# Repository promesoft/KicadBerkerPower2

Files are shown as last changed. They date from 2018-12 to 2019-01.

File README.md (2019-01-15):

# KicadBerkerPower2
Black board

# Mix project
The board consists of 5 separate sections that can be separated. On the backside its easy to see the different ground planes and where to cut the board if needed.

## Status - Rev A Produced 3 of 5 sections working
### Errata
 * Copper goes under ESP12E modules - thereby eliminating the Wifi antenna...
 
### Issues and Notes
 - The two ESP12 modules are difficult to program

 - The Wemos D1 mini section should not be used for 230V but works nevertheless.

 - The rest is fine.

## Physical Construction

## Features

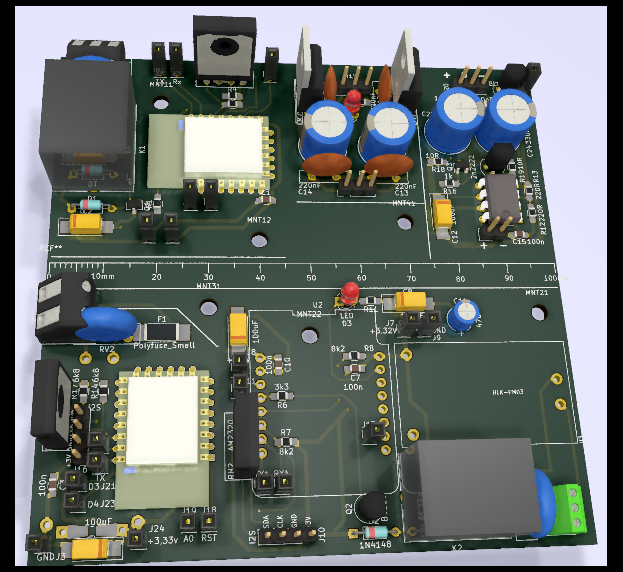
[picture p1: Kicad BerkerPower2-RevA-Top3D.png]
Power

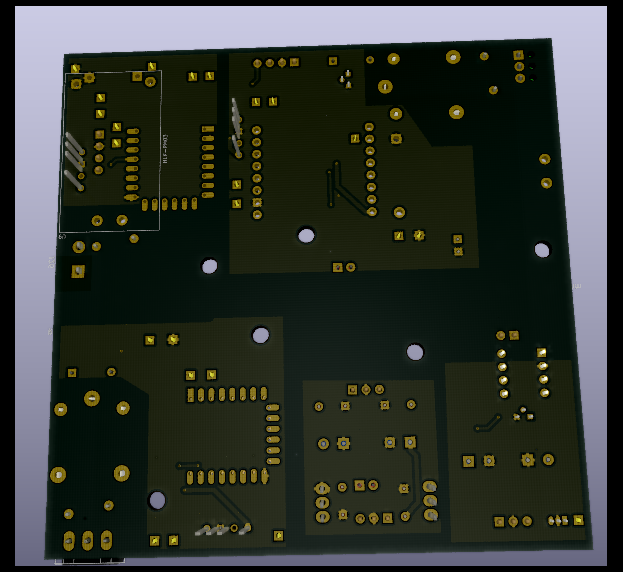
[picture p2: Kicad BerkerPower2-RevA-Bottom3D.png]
Power


# Details
## Wemos D1 mini - section 1
Section 1 is the largest section on the board. It is intended as a development board for section 2 and 3.
Section 1 has an AM2320, a relay and a power supply. Besides this it has breakout of several pins and an LED for debug/information.
### Issues
There is one flaw with section 1 that should be addressed: The pins on the power connector are too close for 230V operation as the centerpin of the relay bridges the live and neutral (calculated to be min 2,3mm between open terminals - 3,2mm for certification) 

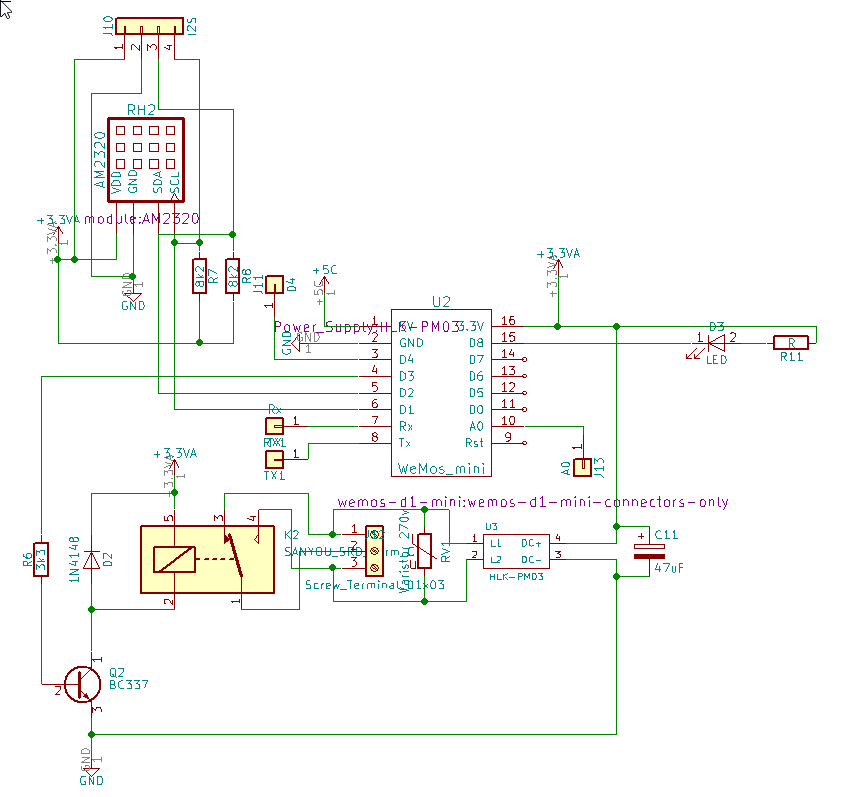
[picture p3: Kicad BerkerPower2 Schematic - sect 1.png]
Section1

### I2S connector 
D1 - SCL

D2 - SDA
### AM2320 
D1 - SCL

D2 - SDA
### Relay
D3 - Active high
### HLK-PM03 PSU
+3v PSU supply if mounted 
Connector not suitable for 230V
Protection: Varistor
External Fuse needed
### Pull down LED
D8 - active low
## ESP12S - Section 2
Section 2 is the smaller than section 1 but with most features of it.
### AM2320 
### Relay
### HLK-PM03 PSU
## ESP12S - Section 3
No reset or programming assistance (pulldn/up etc)
Programming via Rx/Tx (or preprogrammed)
### AM2320 
### Relay
### HLK-PM03 PSU
## PSU - Virtual GDN - "Floating ground section"
Sometimes you only have a single ended supply but need a positive and negative supply.
This little board provides a low power balanced center that can be used as GND. So a +24 V single ended supply becomes a +/-12V supply.

### Input +/- supply
eg +24Vin and a "GNDin"
### Output + 0 - supply
becomes a +12V (same as +24in) GND and -12V (same as GNDin)
### Output regulated +5v GND (78L05)
The +12Vout is fed to a low power regulator for 5V output
## PSU
### Input + 0 - supply
### Output + 0 - regulated supply (78xx and 79xx)

#Cutout

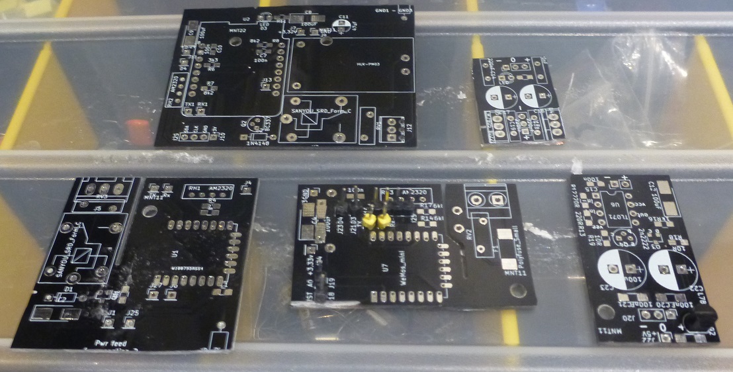
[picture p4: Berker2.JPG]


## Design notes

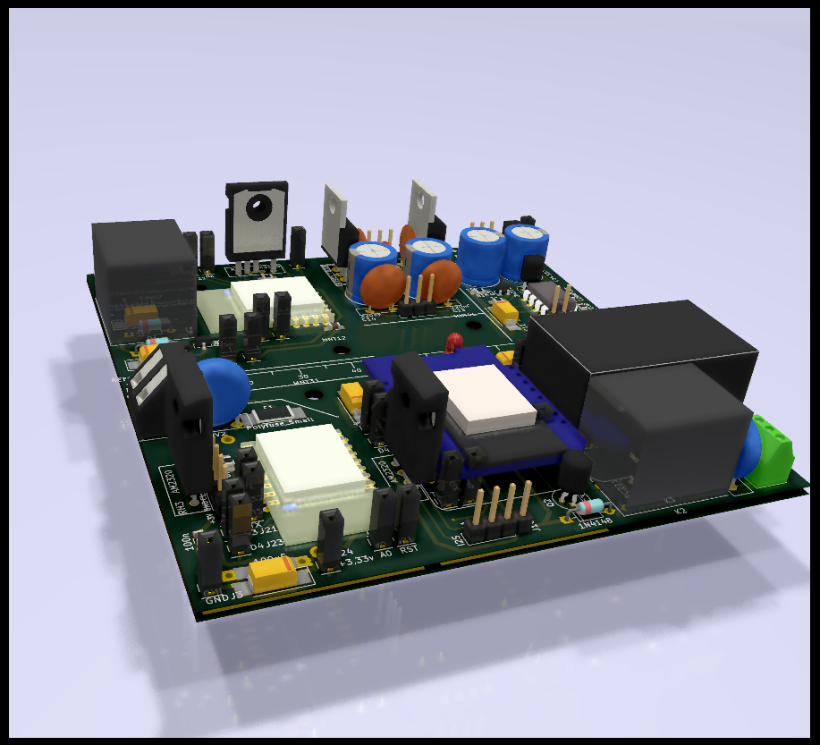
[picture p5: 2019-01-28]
Kicad BerkerPower2-RevA-Top3D2.png

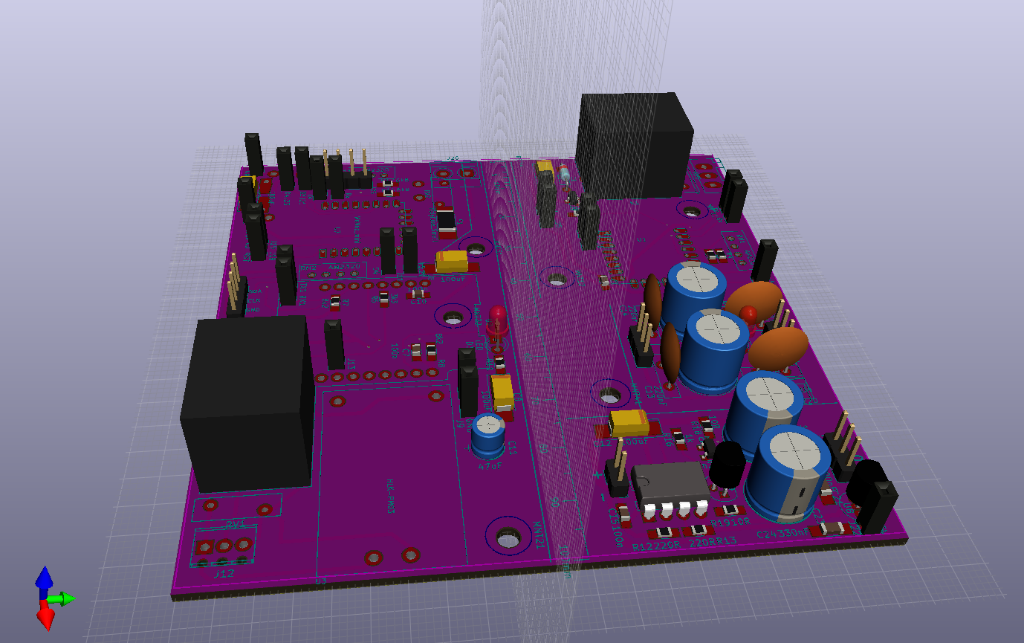
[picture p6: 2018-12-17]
Kicad BerkerPower2 3D.png

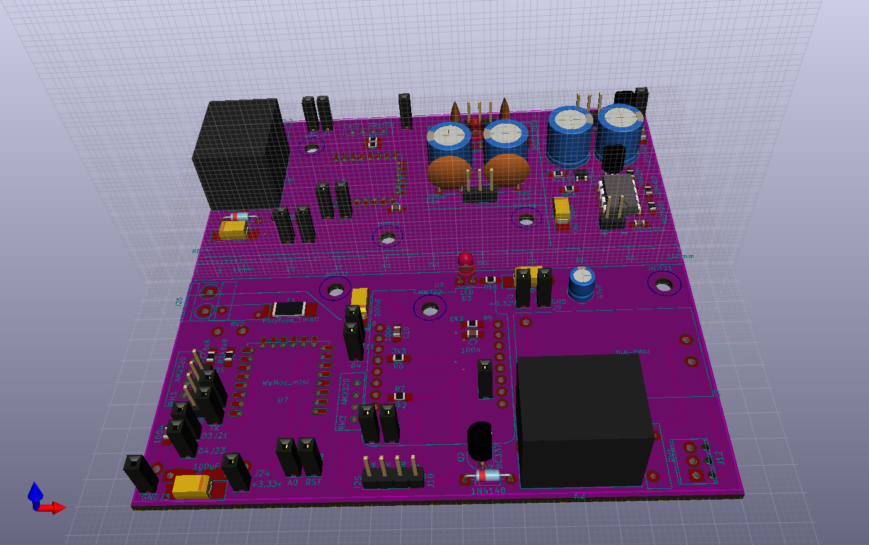
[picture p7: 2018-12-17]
Kicad BerkerPower2a 3D.png

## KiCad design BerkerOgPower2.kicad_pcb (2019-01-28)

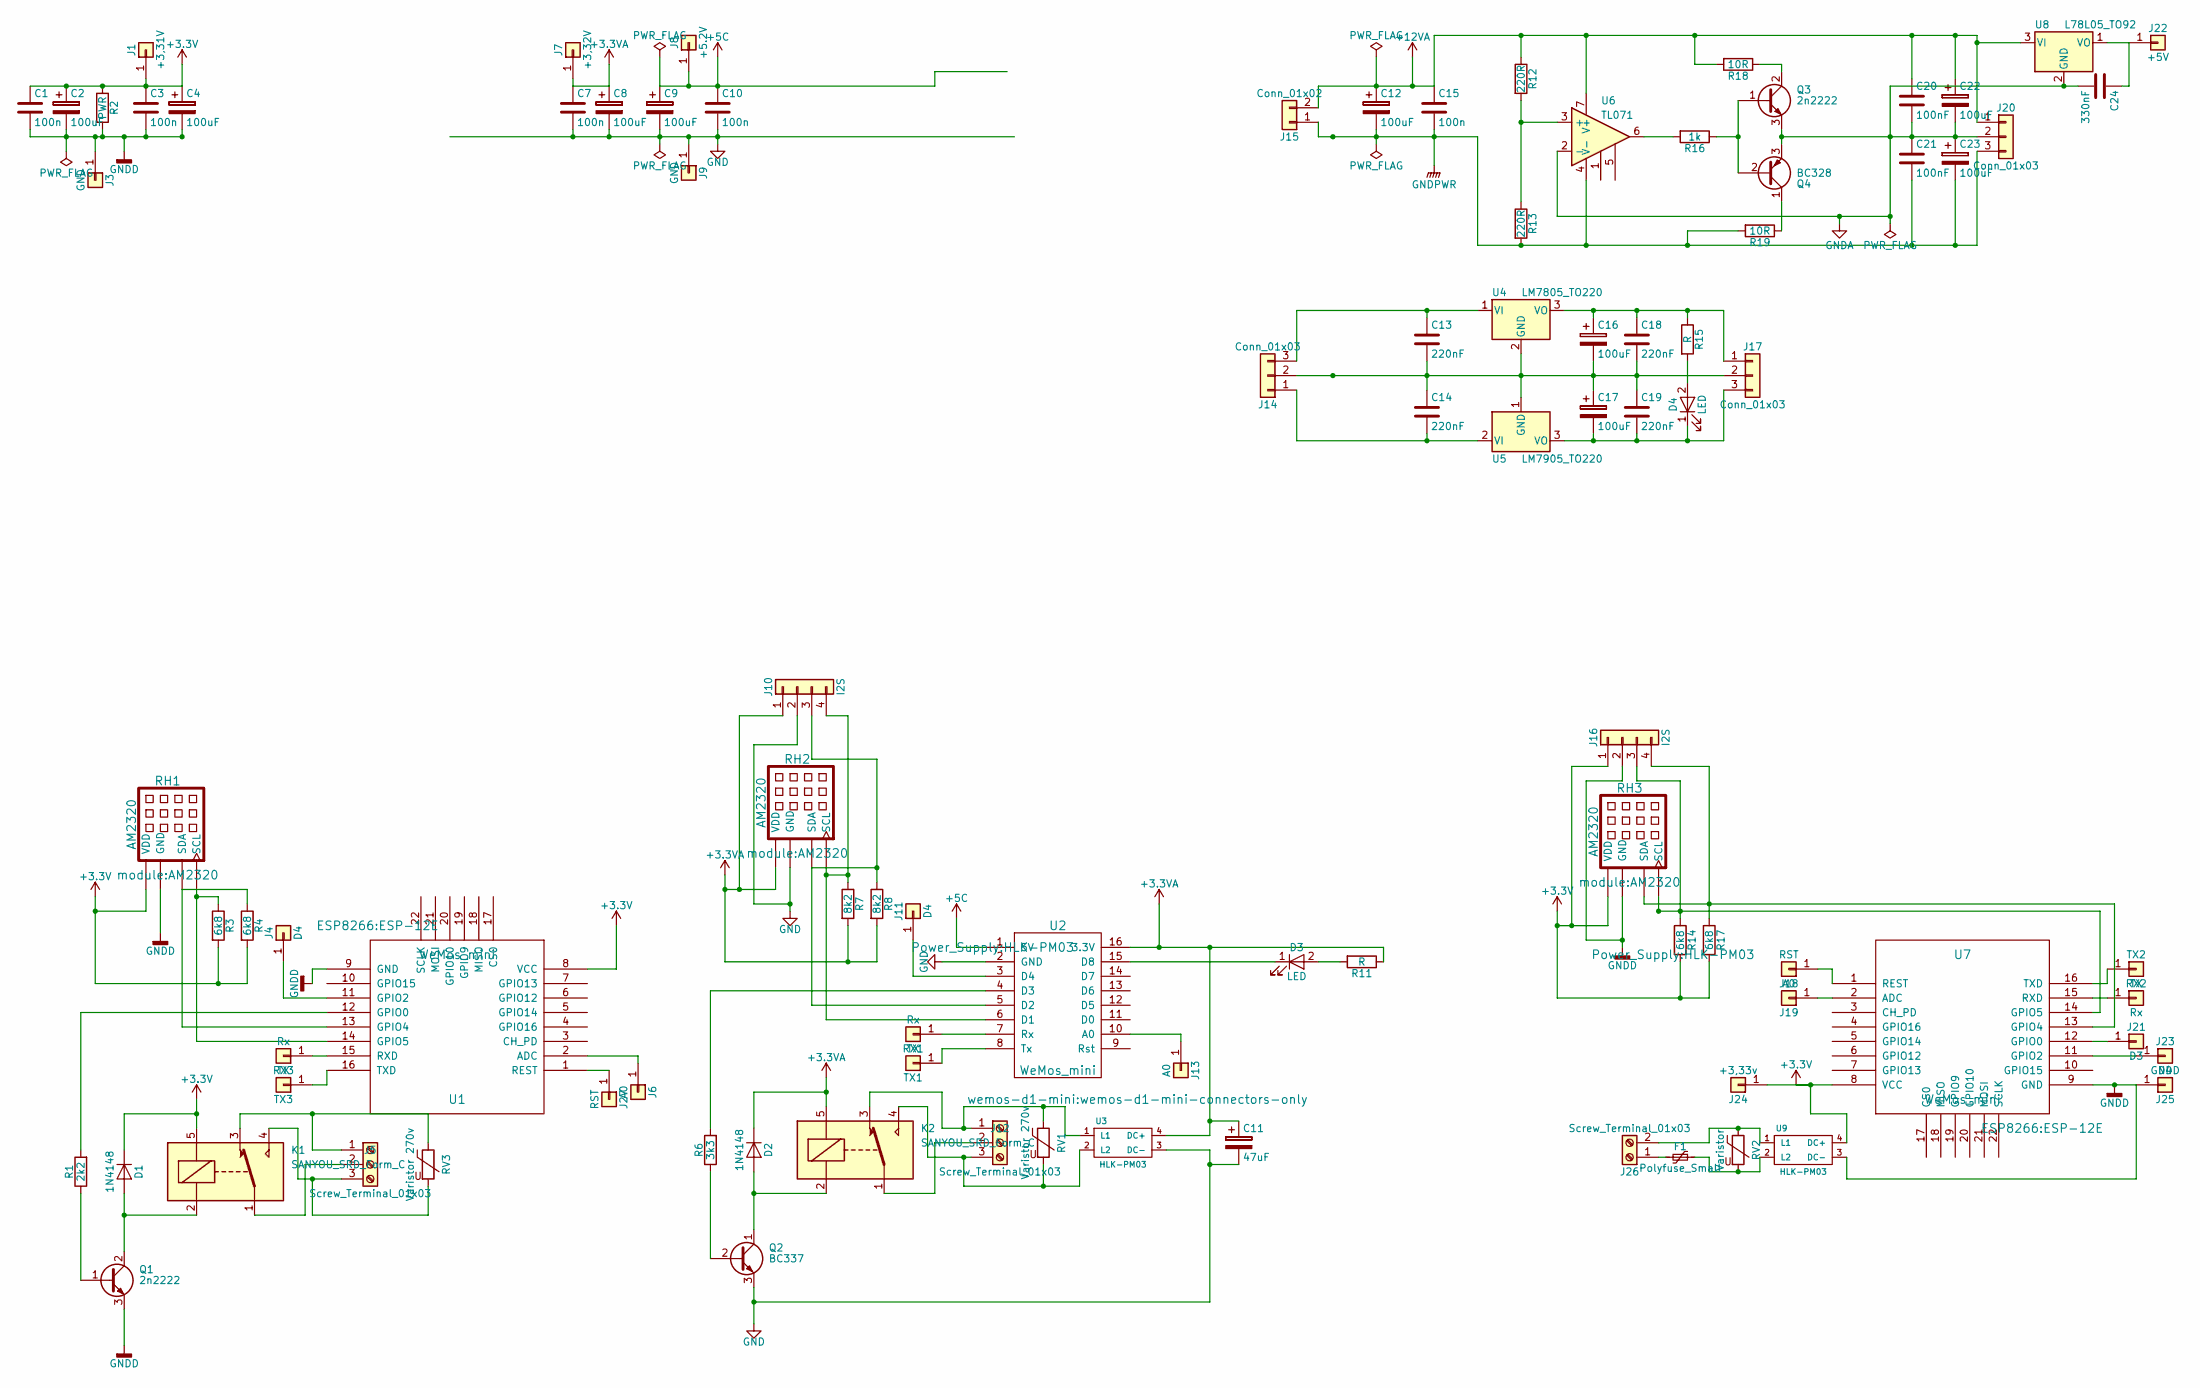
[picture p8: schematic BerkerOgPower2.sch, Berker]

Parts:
C1, C3, C7, C10, C15: 100n; C_0805_HandSoldering
C2, C4, C8, C9, C12: 100uF; CP_Tantalum_Case-C_EIA-6032-28_Hand
C11: 47uF; CP_Radial_D5.0mm_P2.50mm
C13, C14, C18, C19: 220nF; C_Disc_D10.0mm_W2.5mm_P5.00mm
C16, C17, C22, C23: 100uF; CP_Radial_D10.0mm_P3.80mm
C20, C21: 100nF; C_1206_HandSoldering
C24: 330nF; C_1206_HandSoldering
D1, D2: 1N4148; D_DO-35_SOD27_P7.62mm_Horizontal
D3, D4: LED; LED_D3.0mm
F1: Polyfuse_Small; R_2512_HandSoldering
J1: +3,31V; Socket_Strip_Straight_1x01_Pitch2.54mm
J3, J9: GND; Socket_Strip_Straight_1x01_Pitch2.54mm
J4, J11, J23: D4; Socket_Strip_Straight_1x01_Pitch2.54mm
J5: Screw_Terminal_01x03; WAGO_734_3pin_Straight_RuggedPads
J6, J13, J19: A0; Socket_Strip_Straight_1x01_Pitch2.54mm
J7: +3,32V; Socket_Strip_Straight_1x01_Pitch2.54mm
J8: +5.2V; Socket_Strip_Straight_1x01_Pitch2.54mm
J10, J16: I2S; Pin_Header_Straight_1x04_Pitch2.54mm
J12: Screw_Terminal_01x03; TerminalBlock_Phoenix_MPT-2.54mm_3pol
J14, J17, J20: Conn_01x03; Pin_Header_Straight_1x03_Pitch2.54mm
J15: Conn_01x02; Pin_Header_Straight_1x02_Pitch2.54mm
J18, J27: RST; Socket_Strip_Straight_1x01_Pitch2.54mm
J21: D3; Socket_Strip_Straight_1x01_Pitch2.54mm
J22: +5V; Socket_Strip_Straight_1x01_Pitch2.54mm
J24: +3,33v; Socket_Strip_Straight_1x01_Pitch2.54mm
J25: GNDD; Socket_Strip_Straight_1x01_Pitch2.54mm
J26: Screw_Terminal_01x03; TerminalBlock_Phoenix_MKDS1.5-2pol
K1, K2: SANYOU_SRD_Form_C; Relay_SPDT_SANYOU_SRD_Series_Form_C
Q1, Q3: 2n2222; SOT-23
Q2: BC337; TO-92_Molded_Narrow
Q4: BC328; TO-92_Molded_Narrow
R1: 2k2; R_0805_HandSoldering
R2: PWR; Resistor_SMD+THTuniversal_0805to1206_RM10_HandSoldering
R3, R4, R14, R17: 6k8; R_0805_HandSoldering
R6: 3k3; R_0805_HandSoldering
R7, R8: 8k2; R_0805_HandSoldering
R11, R15: R; R_0805_HandSoldering
R12, R13: 220R; R_0805_HandSoldering
R16: 1k; R_0805_HandSoldering
R18, R19: 10R; R_0805_HandSoldering
RH1, RH2, RH3: AM2320
RV1, RV3: Varistor 270v; RV_Disc_D12_W3.9_P7.5
RV2: Varistor; RV_Disc_D12_W3.9_P7.5
RX1, RX2, RX3: Rx; Socket_Strip_Straight_1x01_Pitch2.54mm
TX1, TX2, TX3: TX; Socket_Strip_Straight_1x01_Pitch2.54mm
U1, U7: WeMos_mini; ESP-12E
U2: WeMos_mini; wemos-d1-mini-connectors-only
U3, U9: HLK-PM03
U4: LM7805_TO220; TO-220
U5: LM7905_TO220; TO-220
U6: TL071; DIP-8_W7.62mm
U8: L78L05_TO92; TO-92_Inline_Narrow_Oval

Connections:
+3.3VA: C7.1, C8.1, C11.1, D2.1 (K), J7.1, J10.1, K2.5, R7.2, R8.2, R11.1, RH2.1 (VDD), U2.16 (3.3V), U3.4 (DC+)
+3V3: C1.1, C2.1, C3.1, C4.1, D1.1 (K), J1.1, J16.1, J24.1, K1.5, R2.1, R3.2, R4.2, R14.2, R17.2, RH1.1 (VDD), RH3.1 (VDD), U1.8 (VCC), U7.8 (VCC), U9.4 (DC+)
+5C: C9.1, C10.1, J8.1, U2.1 (5V)
+12VA: C12.1, C15.1, C20.1, C22.1, J15.2, J20.1, R12.1, R18.2, U6.7 (V+), U8.3 (VI)
GND: C7.2, C8.2, C9.2, C10.2, C11.2, J9.1, J10.2, Q2.3 (E), RH2.3 (GND), U2.2 (GND), U3.3 (DC-)
GNDA: C20.2, C21.1, C22.2, C23.1, C24.2, J20.2, Q3.3 (E), Q4.3 (E), U6.2 (-), U8.2 (GND)
GNDD: C1.2, C2.2, C3.2, C4.2, J3.1, J16.2, J25.1, Q1.3 (E), R2.2, RH1.3 (GND), RH3.3 (GND), U1.9 (GND), U7.9 (GND), U9.3 (DC-)
GNDPWR: C12.2, C15.2, C21.2, C23.2, J15.1, J20.3, R13.2, R19.2, U6.4 (V-)
unnamed: C13.1, J14.3, U4.1 (VI)
unnamed: C13.2, C14.1, C16.2, C17.1, C18.2, C19.1, J14.2, J17.2, U4.2 (GND), U5.1 (GND)
unnamed: C14.2, J14.1, U5.2 (VI)
unnamed: C16.1, C18.1, J17.1, R15.1, U4.3 (VO)
unnamed: C17.2, C19.2, D4.1 (K), J17.3, U5.3 (VO)
unnamed: C24.1, J22.1, U8.1 (VO)
unnamed: D1.2 (A), K1.2, Q1.2 (C)
unnamed: D2.2 (A), K2.2, Q2.1 (C)
unnamed: D3.1 (K), U2.15 (D8)
unnamed: D3.2 (A), R11.2
unnamed: D4.2 (A), R15.2
unnamed: F1.1, RV2.2, U9.2 (L2)
unnamed: F1.2, J26.1
unnamed: J4.1, U1.11 (GPIO2)
unnamed: J5.1, K1.3, RV3.1
unnamed: J5.2, K1.1
unnamed: J5.3, K1.4, RV3.2
unnamed: J6.1, U1.2 (ADC)
unnamed: J10.3, R8.1, RH2.2 (SDA), U2.5 (D2)
unnamed: J10.4, R7.1, RH2.4 (SCL), U2.6 (D1)
unnamed: J11.1, U2.3 (D4)
unnamed: J12.1, K2.3, RV1.1, U3.1 (L1)
unnamed: J12.2, K2.1
unnamed: J12.3, K2.4, RV1.2, U3.2 (L2)
unnamed: J13.1, U2.10 (A0)
unnamed: J16.3, R14.1, RH3.4 (SCL), U7.14 (GPIO5)
unnamed: J16.4, R17.1, RH3.2 (SDA), U7.13 (GPIO4)
unnamed: J18.1, U7.1 (REST)
unnamed: J19.1, U7.2 (ADC)
unnamed: J21.1, U7.12 (GPIO0)
unnamed: J23.1, U7.11 (GPIO2)
unnamed: J26.2, RV2.1, U9.1 (L1)
unnamed: J27.1, U1.1 (REST)
unnamed: Q1.1 (B), R1.1
unnamed: Q2.2 (B), R6.1
unnamed: Q3.1 (B), Q4.2 (B), R16.1
unnamed: Q3.2 (C), R18.1
unnamed: Q4.1 (C), R19.1
unnamed: R1.2, U1.12 (GPIO0)
unnamed: R3.1, RH1.4 (SCL), U1.14 (GPIO5)
unnamed: R4.1, RH1.2 (SDA), U1.13 (GPIO4)
unnamed: R6.2, U2.4 (D3)
unnamed: R12.2, R13.1, U6.3 (+)
unnamed: R16.2, U6.6
unnamed: RX1.1, U2.7 (Rx)
unnamed: RX2.1, U7.15 (RXD)
unnamed: RX3.1, U1.15 (RXD)
unnamed: TX1.1, U2.8 (Tx)
unnamed: TX2.1, U7.16 (TXD)
unnamed: TX3.1, U1.16 (TXD)

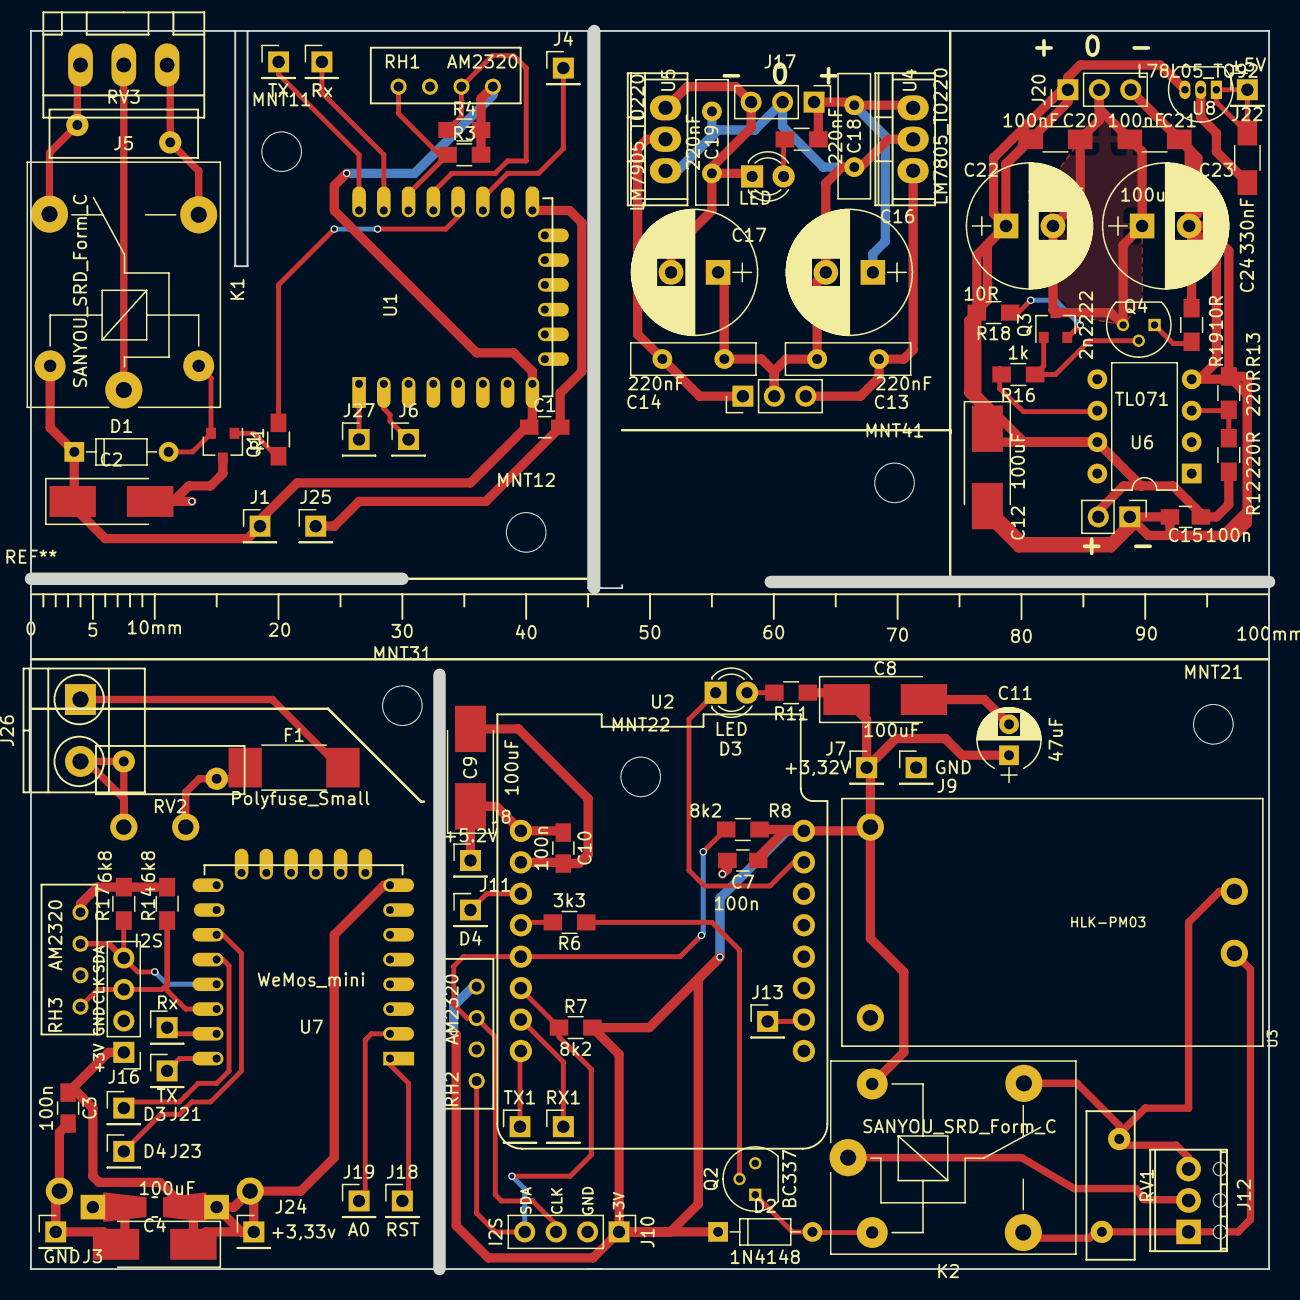
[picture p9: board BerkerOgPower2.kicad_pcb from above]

Board: 2 copper layers, 100.0 x 100.0 mm, 102 parts (1 on the bottom side), 58 nets.

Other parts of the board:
MNT11, MNT12, MNT21, MNT22, MNT31, MNT41: MountingHole_3.2mm_M3

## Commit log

2018-12-17 Commit after project creation
    Project performed outside Git...
    [BerkerOgPower2-B.Cu.gbl, BerkerOgPower2-B.Mask.gbs, BerkerOgPower2-B.Paste.gbp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]
2018-12-17 Pictures
    3D and schematic
2018-12-25 Update README.md
    cut out
2019-01-15 New 3D
    [BerkerOgPower2.kicad_pcb]
2019-01-15 cleanup folders
    [BerkerOgPower2-B.Cu.gbl, BerkerOgPower2-B.Mask.gbs, BerkerOgPower2-B.Paste.gbp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]
2019-01-28 3D updated + Picture
    [BerkerOgPower2.kicad_pcb]
2019-01-28 New 3D models
    [BerkerOgPower2.kicad_pcb]
